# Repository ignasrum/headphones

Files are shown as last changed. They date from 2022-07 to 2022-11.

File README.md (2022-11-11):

# 3D printable headphones

Features:
* 3D printable
* 40 mm drivers
* Utilizes Beyerdynamic DT770/DT880/DT990 earpads and headband
* Mini XLR socket
* Open/closed versions of the earcups
* Designed with durability and repairability in mind

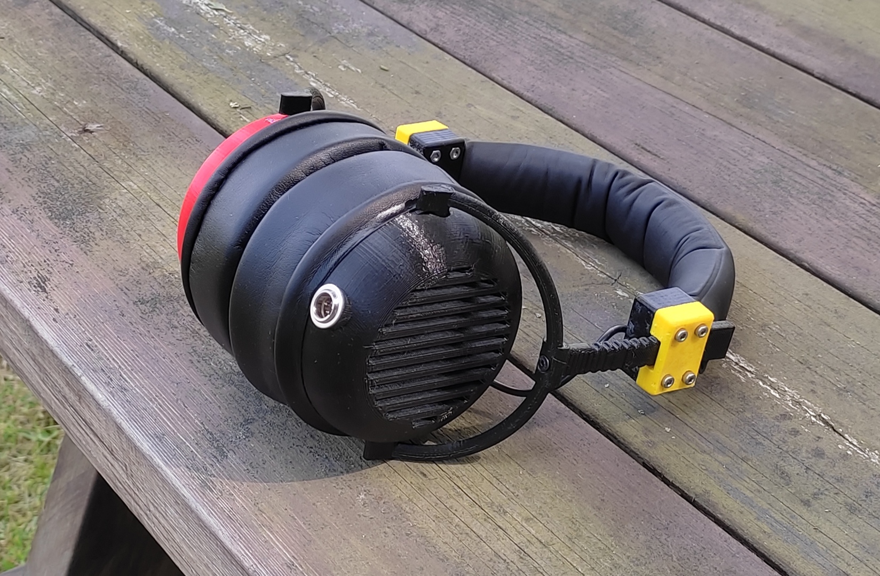
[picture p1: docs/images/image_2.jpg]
prototype_image_2


### Parts to assemble:
| Count | Part | Filament | Notes |
|:-----:|:---:|:---:|:---:|
| 1 | earcup | Hard* | Houses the driver. |
| 1 | earcup_xlr | Hard* | Houses the driver and the mini XLR socket. |
| 2 | driver_plate | Hard* | Holds the driver. Inserted into earcup. |
| 2 | driver_plate_ring | Hard* | Holds the driver_plate in place in the earcup. |
| 4 | driver_bracket | Soft** | Holds down the driver to the driver_plate. |
| 2 | driver_gasket | Hard* | Gasket for the driver. Inserted into driver_plate. |
| 2 | earcup_band | Hard* | Goes around the earcup. |
| 1 | headband | Hard* | |
| 2 | slider_part_1 | Hard* | Part 1 of the slider mechanism. |
| 2 | slider_part_2 | Soft** | Part 2 of the slider mechanism. |
| 2 | slider_rod | Hard* | Slides into the slider part 1 + part 2. |
| 2 | 40 mm driver | | Inserted into driver_plate. |
| 1 | Mini XLR cable | | |
| 1 | Mini XLR socket | | Mounts to earcup_xlr. Mounting hole diameter is 11.4 mm. |
| 1 | 3-4 mm wire | | 2 wires inside. Connects the earcups/drivers. |
| 2 | DT-series earpads | | Attaches to the earcups. |
| 1 | DT-series headband | | Attaches to the headband. |
| 8 | M3 insert | | Heated and inserted into driver_plate. |
| 8 | M3 nut | | Inserted into slider_part_1. |
| 8 | 25mm? M3 screw | | Screws for the slider mechanism. |
| 8 | 4mm M3 screw | | Screws the driver_bracket to driver_plate. |
| 2 | 10mm M3 screw | | Screws the slider_rod to earcup_band. |
| 2 | 73mm diameter felt fabric circle | | Optional: used for tuning the sound of the open earcups. |

\* Filaments such as PLA, PETG etc.

\** Filaments such as TPU, TPC, TPA etc.

### Notes
* Mirror the parts depending on your setup (cable on left/right earcup etc).
* Use as small and narrow M3 inserts as possible, some of the cheaper/wider ones may not fit.
* Use countersunk screws.

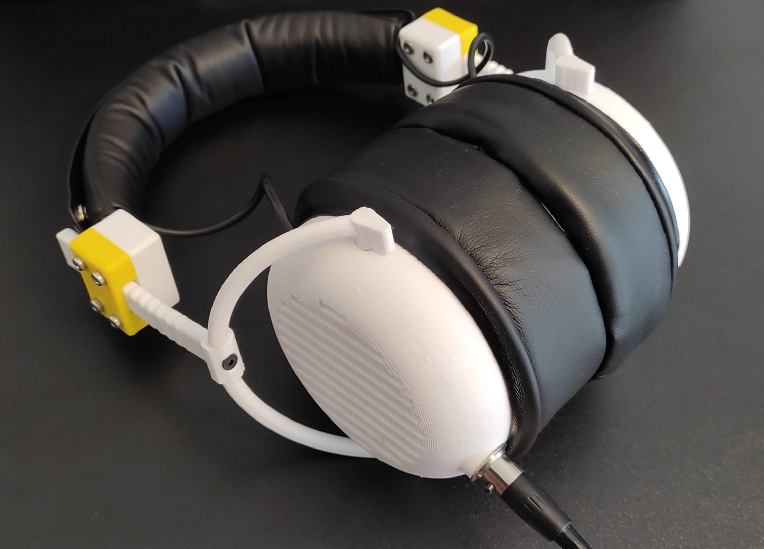
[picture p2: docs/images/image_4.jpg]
prototype_image_1


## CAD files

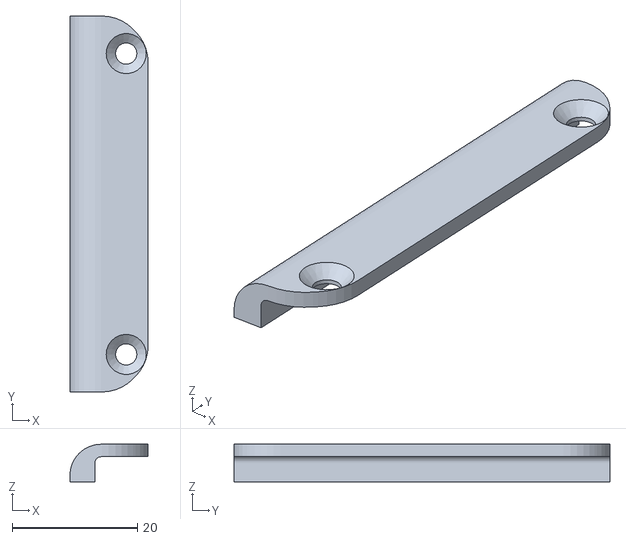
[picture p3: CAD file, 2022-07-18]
stl/driver_bracket/driver_bracket.stl
12.5 x 60.0 x 6.00

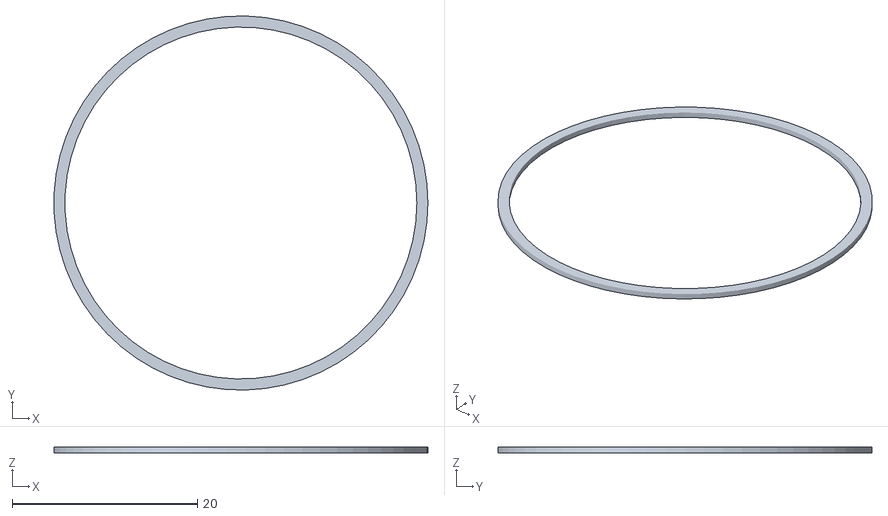
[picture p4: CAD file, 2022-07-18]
stl/driver_gasket/driver_gasket.stl
40.4 x 40.4 x 0.6

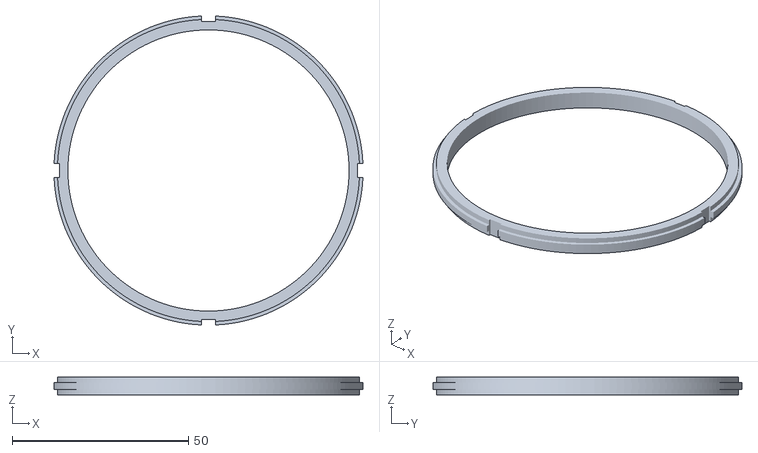
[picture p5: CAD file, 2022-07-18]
stl/driver_plate_ring/driver_plate_ring.stl
87.7 x 87.7 x 5.00

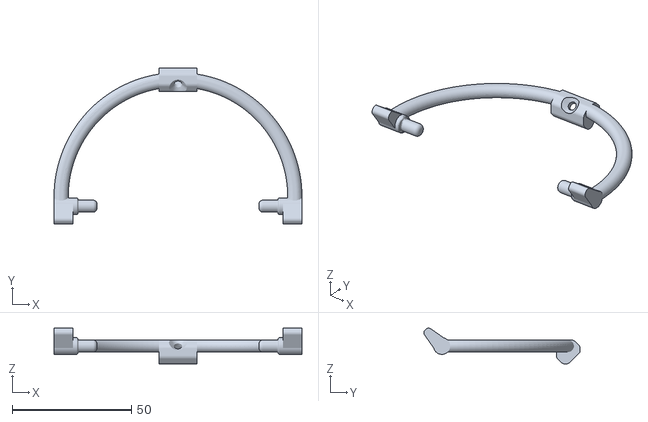
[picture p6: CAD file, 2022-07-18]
stl/earcup_band/earcup_band.stl
104.0 x 65.5 x 15.0

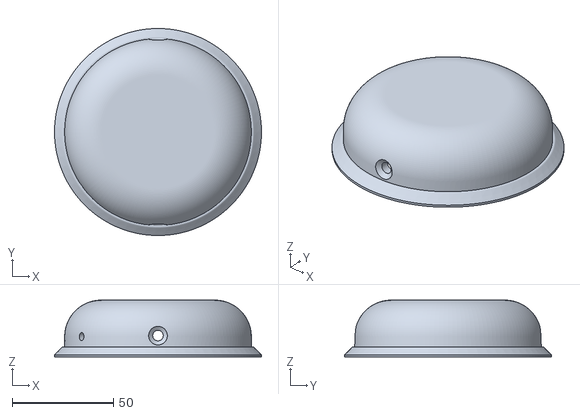
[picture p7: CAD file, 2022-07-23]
stl/earcup_closed/earcup_closed.stl
102.0 x 102.0 x 28.0

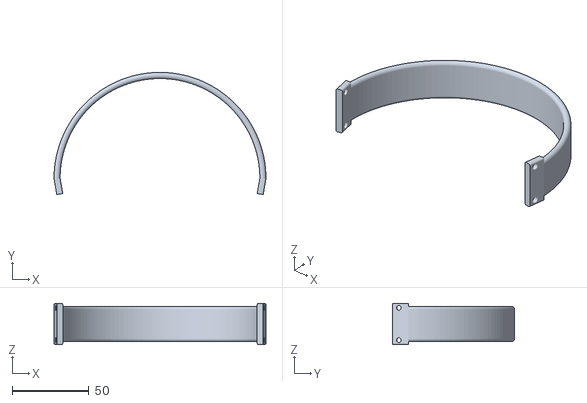
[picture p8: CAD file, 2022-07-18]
stl/headband/headband.stl
138.0 x 79.5 x 27.0

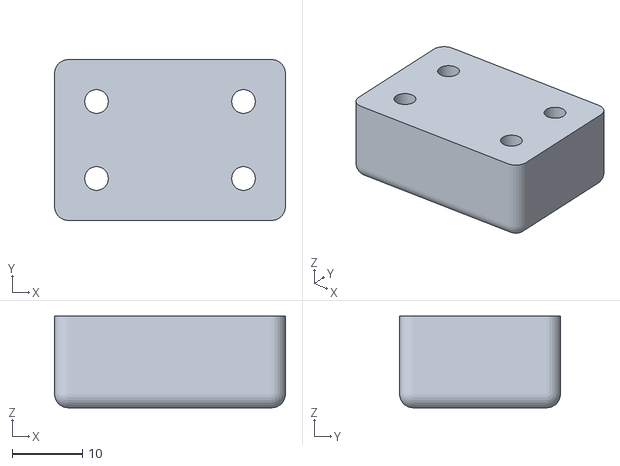
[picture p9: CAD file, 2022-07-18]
stl/slider_part_1/slider_part_1.stl
33.0 x 23.0 x 13.1

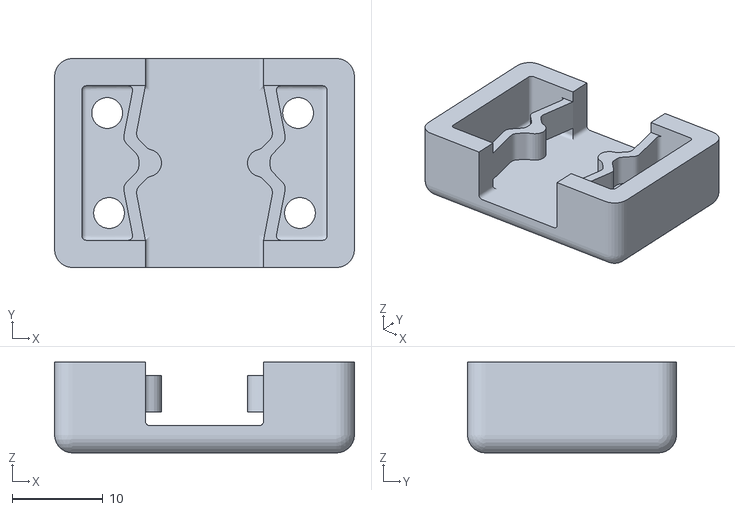
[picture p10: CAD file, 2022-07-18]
stl/slider_part_2/slider_part_2.stl
33.0 x 23.0 x 10.0

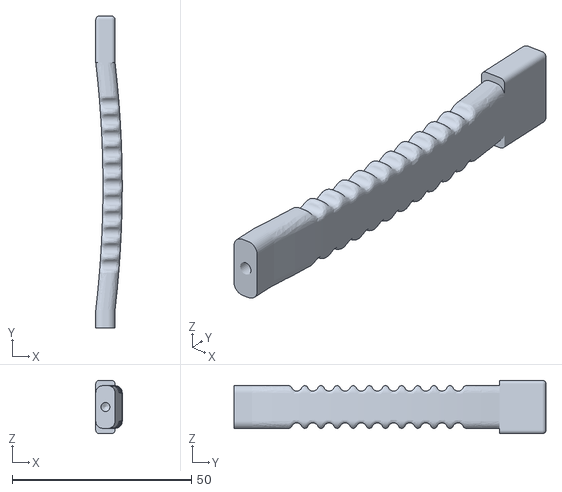
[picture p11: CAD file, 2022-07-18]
stl/slider_rod/slider_rod.stl
7.40 x 87.0 x 14.9

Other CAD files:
stl/earcup_closed/earcup_closed_xlr.stl

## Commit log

2022-07-18 initial commit of stls
    [driver_bracket.stl, driver_gasket.stl, driver_plate_ring.stl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]
2022-07-18 added an image of the prototype
2022-07-18 updated slider_rod.stl (curved and longer)
    [slider_rod.stl]
2022-07-23 added closed earcups
    [earcup_closed.stl, earcup_closed_xlr.stl]
